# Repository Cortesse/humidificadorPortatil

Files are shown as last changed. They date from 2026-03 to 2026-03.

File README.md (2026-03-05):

# Humidificador Ultrasónico Portátil

Sistema electrónico para el control de un humidificador ultrasónico portátil basado en un microcontrolador ESP32.
El proyecto integra el diseño de hardware, firmware y documentación técnica necesaria para el funcionamiento del dispositivo.

El sistema permite controlar el funcionamiento del humidificador, monitorear el estado de la batería y gestionar los diferentes modos de operación del equipo.

---

# Descripción del Proyecto

Este proyecto consiste en el desarrollo de la electrónica de control para un humidificador ultrasónico alimentado por batería.

El sistema utiliza un microcontrolador **ESP32** para gestionar el funcionamiento del dispositivo, incluyendo:

* Control del módulo generador de niebla (humidificador)
* Monitoreo del nivel de batería
* Gestión de estados de funcionamiento
* Visualización de información en display
* Optimización del consumo energético

El dispositivo está diseñado para operar con baterías recargables y utiliza un convertidor **DC-DC boost** para elevar el voltaje cuando es necesario para el funcionamiento del sistema.

---

# Funcionalidades

* Control del módulo humidificador
* Medición del nivel de batería
* Indicador de estado del sistema
* Modos de operación (READY / RUN)
* Conversión DC-DC para regulación de voltaje
* Gestión eficiente del consumo de energía

---

# Arquitectura del Sistema

El sistema se compone de los siguientes bloques principales:

**Batería recargable**
Fuente de alimentación principal del dispositivo.

**Convertidor DC-DC Boost**
Eleva el voltaje de la batería cuando es necesario para alimentar el sistema.

**Microcontrolador ESP32**
Encargado del control del sistema, lectura de sensores y gestión de los estados de funcionamiento.

**Módulo Humidificador Ultrasónico**
Genera la niebla mediante vibración ultrasónica.

**Sistema de medición de batería**
Permite monitorear el estado de carga de la batería mediante el microcontrolador.

**Display / interfaz de usuario**
Muestra información sobre el estado del sistema.

---

# Estructura del Repositorio

Los archivos del proyecto se organizan de la siguiente manera:

```
/humidificador
│
├── firmware/        # Código del ESP32
├── hardware/        # Esquemáticos y PCB
├── docs/            # Documentación del proyecto
├── datasheets/      # Hojas de datos de componentes
└── simulations/     # Archivos de simulación
```

---

# Hardware Principal

* Microcontrolador **ESP32**
* Convertidor **DC-DC Boost**
* Batería recargable
* Módulo humidificador ultrasónico
* Display de estado
* Circuito de medición de batería

---

# Herramientas Utilizadas

* **Arduino IDE** para el desarrollo del firmware
* Software de diseño electrónico (KiCad / EasyEDA / similar)
* Git para control de versiones

---

# Objetivo del Proyecto

Desarrollar un sistema electrónico compacto, eficiente y confiable para el control de un humidificador ultrasónico portátil, integrando hardware y firmware en una arquitectura modular y documentada.

---

# Estado del Proyecto

En desarrollo.

---

# Autores

Agostini, Emiliano y Cortesse, Agustín

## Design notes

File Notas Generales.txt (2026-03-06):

---------- Diagrama ESP32-C3Mini ----------

https://wiki.icbbuy.com/doku.php?id=developmentboard:esp32-c3mini#schematic

https://docs.espressif.com/projects/esp-hardware-design-guidelines/en/latest/esp32c3/schematic-checklist.html (No es FH4 o FN4)

https://forum.arduino.cc/t/unable-to-program-esp32-c3fh4/1405288

https://esp32.com/viewtopic.php?t=39362

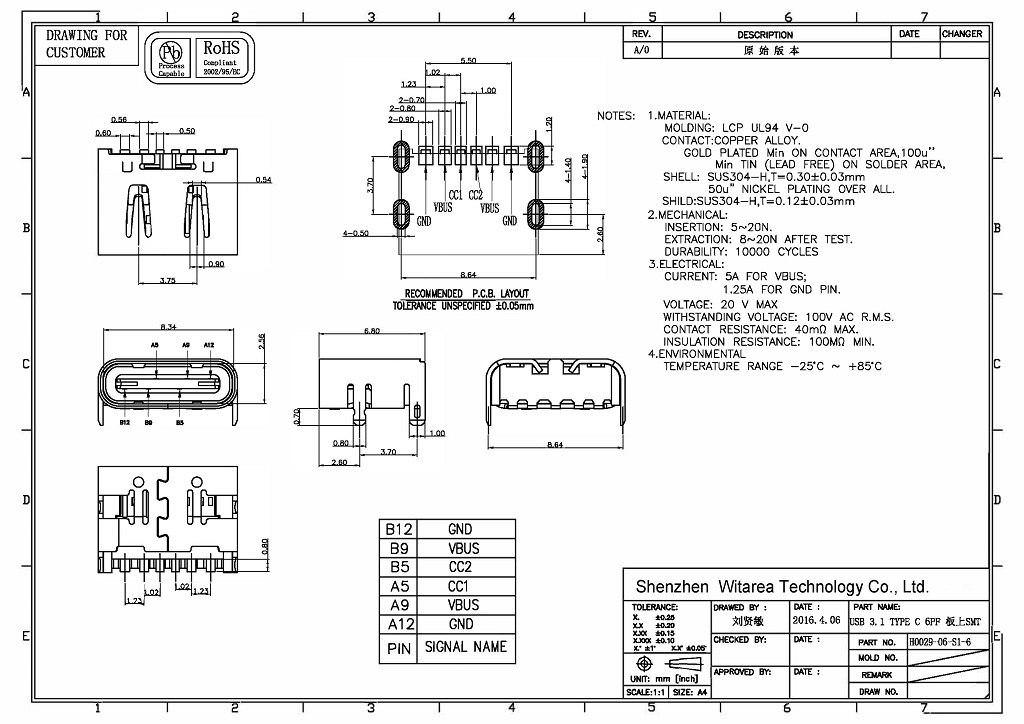
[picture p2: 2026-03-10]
datasheets/Imagenes/usbC.jpg

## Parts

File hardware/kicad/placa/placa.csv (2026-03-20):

Reference | Value
C1,C2,C11,C12 | 10uF
C3,C6,C7,C8,C9,C10,C15 | 100nF
C4,C5 | 22nF
C13,C14 | 15pF
D1,D2 | LED
D3 | SS14
J1 | USB-TYPE-C-008
J2 | Bateria
J3 | OLED SSD1306
J4 | TTP223
J5 | UART
J6 | ULTRASONIDO
L1 | 10u 2A 4x4mm
L2 | 220uH D7.8xL5.5
Q1 | AO3400A
R1,R2,R6,R7 | 1kΩ
R3 | 1.2kΩ
R4 | 3.3kΩ
R5,R9,R11,R12 | 10kΩ
R8 | 75kΩ
R10 | 10Ω
SW1,SW2,SW3 | SW_SPST
TH2 | Thermistor_NTC_US
U1 | TP4056
U2 | MT3608
U3 | AMS1117
U4 | ESP32-C3FH4
U5 | TC4427xOA
X1 | 40MHz, 15pF

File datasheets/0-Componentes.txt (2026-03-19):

| Item | Descripcion		| Codigo		| Link proveedor 
| ---- | --- | ---	| ---
| 1 | Microcontrolador	| ESP32-C3FH4		| https://jlcpcb.com/partdetail/EspressifSystems-ESP32C3FH4/C2858491 
| 2 | IC Conversor dc-dc	| MT3608		| https://jlcpcb.com/partdetail/XI_AN_AerosemiTech-MT3608/C84817 
| 3 | IC Carga bateria	| TP4056-42-ESOP8	| https://jlcpcb.com/partdetail/17264-TP4056_42ESOP8/C16581
| 4 | Display		| HS91L02W2C01		| https://jlcpcb.com/partdetail/HS-HS91L02W2C01/C5248081
| 5 | Oscilador		| X322540MPB4SI		| https://jlcpcb.com/partdetail/YXC_CrystalOscillators-X322540MPB4SI/C9010
| 6 | Conector Type C	| USB-TYPE-C-008	| https://jlcpcb.com/partdetail/DEALON-USB_TYPE_C008/C2927028
| 7 | Regulador lineal	| AMS1117-3.3S		| https://jlcpcb.com/partdetail/323916-AMS1117_33S/C347256

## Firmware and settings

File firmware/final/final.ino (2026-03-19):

#include <Wire.h>
#include <Adafruit_GFX.h>
#include <Adafruit_SSD1306.h>

/* =========================================================
   CONFIGURACIÓN DE HARDWARE (PINES)
   ========================================================= */
#define PIN_ADC_BAT   3

#define PIN_I2C_SDA   4
#define PIN_I2C_SCL   5

#define PIN_TTP       2
#define PIN_HUM       6

#define PIN_CHRG      7
#define PIN_STDBY     1

/* =========================================================
   CONFIGURACIÓN DE BATERÍA
   ========================================================= */
const float BAT_MAX_VOLT = 4.05;
const float BAT_MIN_VOLT = 1.55;

/* =========================================================
   CONFIGURACIÓN OLED
   ========================================================= */
#define SCREEN_WIDTH  128
#define SCREEN_HEIGHT 32

Adafruit_SSD1306 display(SCREEN_WIDTH, SCREEN_HEIGHT, &Wire, -1);

/* =========================================================
   ENUMERACIONES
   ========================================================= */
enum EstadoSistema {
  EST_READY,
  EST_RUN,
  EST_FULL,
  EST_LOW
};

enum EstadoCarga {
  CARGA_IDLE,
  CARGA_CHARGING,
  CARGA_FULL
};

/* =========================================================
   VARIABLES GLOBALES
   ========================================================= */
bool ttpAnterior   = LOW;
bool humEncendido  = false;

float vBatFiltrada = 0;

/* =========================================================
   CAPA HARDWARE
   ========================================================= */
EstadoCarga obtenerEstadoCarga() {

  bool chrg  = digitalRead(PIN_CHRG);
  bool stdby = digitalRead(PIN_STDBY);

  if (chrg == LOW)  return CARGA_CHARGING;
  if (stdby == LOW) return CARGA_FULL;

  return CARGA_IDLE;
}

float leerBateria() {

  long suma = 0;

  for (int i = 0; i < 100; i++) {
    suma += analogRead(PIN_ADC_BAT);
    delay(2);
  }

  float adcProm = suma / 100.0;
  float voltADC = (adcProm / 4095.0) * 3.6;
  float voltBat = (voltADC * (122.0 / 22.0)) * 0.831;

  return voltBat;
}

/* =========================================================
   CAPA DE PROCESAMIENTO
   ========================================================= */
int voltPor(float v) {

  float p;

  if (v >= BAT_MAX_VOLT)      p = 100;
  else if (v <= BAT_MIN_VOLT) p = 0;
  else p = (v - BAT_MIN_VOLT) * 100.0 / (BAT_MAX_VOLT - BAT_MIN_VOLT);

  int por5 = round(p / 5.0) * 5;
  return constrain(por5, 0, 100);
}

int voltPorEstable(float v) {

  static int porcentajeActual = -1;
  static float vRef = 0;

  int nuevo = voltPor(v);

  if (porcentajeActual < 0) {
    porcentajeActual = nuevo;
    vRef = v;
    return porcentajeActual;
  }

  if (abs(v - vRef) > 0.06) {
    porcentajeActual = nuevo;
    vRef = v;
  }

  return porcentajeActual;
}

EstadoSistema obtenerEstadoSistema(int porcentaje) {

  if (porcentaje <= 30) return EST_LOW;
  if (porcentaje >= 95) return EST_FULL;

  if (humEncendido) return EST_RUN;

  return EST_READY;
}

/* =========================================================
   CAPA DE ACTUACIÓN
   ========================================================= */
void dispararHumidificador() {

  digitalWrite(PIN_HUM, LOW);
  delay(10);
  digitalWrite(PIN_HUM, HIGH);
}

/* =========================================================
   CAPA DE INTERFAZ
   ========================================================= */
void dibujarIconoBateria(int porcentaje) {

  const int x = 4;
  const int y = 6;
  const int w = 48;
  const int h = 20;

  display.drawRect(x, y, w, h, SSD1306_WHITE);
  display.fillRect(x + w, y + 6, 3, 8, SSD1306_WHITE);

  const int margen = 2;
  const int anchoUtil = w - 2 * margen;
  int fill = map(porcentaje, 0, 100, 0, anchoUtil);

  display.fillRect(
    x + margen,
    y + margen,
    fill,
    h - 2 * margen,
    SSD1306_WHITE
  );
}

void dibujarTextoEstado(EstadoSistema estado, EstadoCarga carga) {

  display.setTextSize(1);
  display.setTextColor(SSD1306_WHITE);

  // ===== Estado del sistema (principal) =====
  switch (estado) {

    case EST_READY:
      display.setCursor(68, 12);
      display.print("READY");
      break;

    case EST_RUN:
      display.setCursor(68, 12);
      display.print("RUN");
      break;

    case EST_FULL:
      display.setCursor(68, 6);
      display.print("BATTERY");
      display.setCursor(68, 18);
      display.print("FULL");
      break;

    case EST_LOW:
      display.setCursor(68, 6);
      display.print("BATTERY");
      display.setCursor(68, 18);
      display.print("LOW");
      break;
  }

  // ===== Estado de carga (secundario) =====
  if (carga == CARGA_CHARGING) {
    display.setCursor(68, 0);
    display.print("CHG");
  }

  if (carga == CARGA_FULL) {
    display.setCursor(68, 0);
    display.print("FULL");
  }
}

/* =========================================================
   SETUP
   ========================================================= */
void setup() {

  analogReadResolution(12);
  analogSetPinAttenuation(PIN_ADC_BAT, ADC_11db);

  pinMode(PIN_TTP, INPUT_PULLDOWN);
  pinMode(PIN_HUM, OUTPUT);
  digitalWrite(PIN_HUM, HIGH);

  pinMode(PIN_CHRG, INPUT_PULLUP);
  pinMode(PIN_STDBY, INPUT_PULLUP);

  Serial.begin(115200);

  Wire.begin(PIN_I2C_SDA, PIN_I2C_SCL);
  Wire.setClock(100000);

  display.begin(SSD1306_SWITCHCAPVCC, 0x3C);
  display.clearDisplay();
  display.display();
}

/* =========================================================
   LOOP
   ========================================================= */
void loop() {

  // ===== TTP =====
  bool ttpActual = digitalRead(PIN_TTP);

  if (ttpAnterior == HIGH && ttpActual == LOW) {
    humEncendido = !humEncendido;
    dispararHumidificador();
  }

  ttpAnterior = ttpActual;

  // ===== BATERÍA =====
  if (!humEncendido) {
    vBatFiltrada = leerBateria();
  }

  int porcentaje = voltPorEstable(vBatFiltrada);

  // ===== ESTADOS =====
  EstadoCarga carga = obtenerEstadoCarga();
  EstadoSistema estado = obtenerEstadoSistema(porcentaje);

  // ===== DISPLAY =====
  display.clearDisplay();
  dibujarIconoBateria(porcentaje);
  dibujarTextoEstado(estado, carga);
  display.display();

  delay(200);
}

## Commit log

2026-03-06 ESP32 Esquemas encotrados
2026-03-20 Cambio de capacitores
    [placa.csv]
